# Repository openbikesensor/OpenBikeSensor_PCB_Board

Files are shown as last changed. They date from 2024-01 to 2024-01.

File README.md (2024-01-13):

# OpenBikeSensor PCB

Dieses Repository enthält die offiziellen PCBs des OpenBikeSensor Projektes.
Sie sind in der freien Software [KiCad](https://www.kicad.org/) erstellt und
können damit modifiziert werden.

## Versionen

### OpenBikeSensor

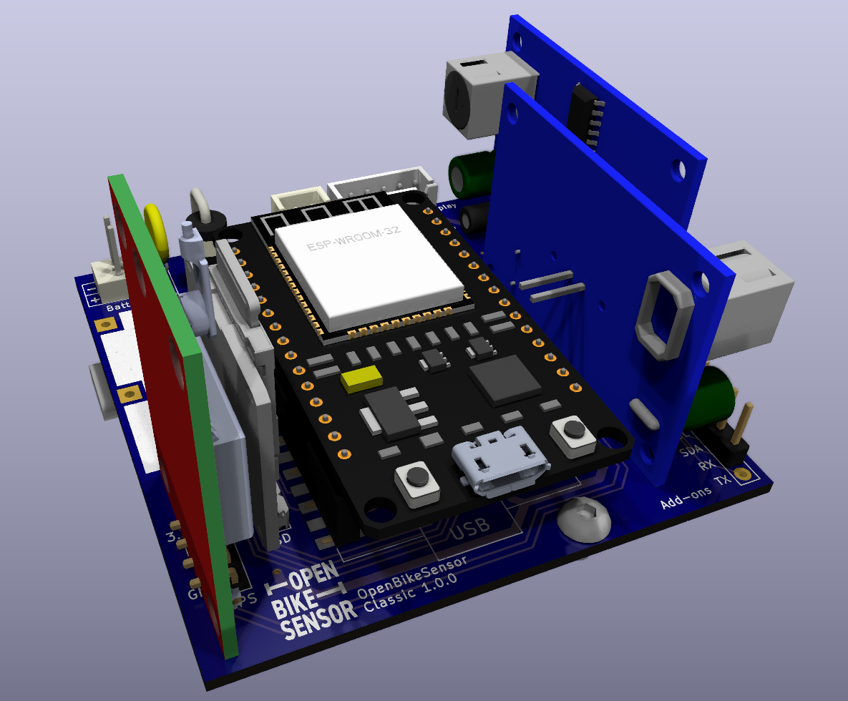
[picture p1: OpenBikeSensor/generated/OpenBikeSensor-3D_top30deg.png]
OpenBikeSensor 3D-Render


Dies ist der Standard-OpenBikeSensor als eigenständiges Gerät, hergestellt aus
vielen fertig verfügbaren Modulen (ESP32 Devkit, GPS, SD-Karten-Modul,
Ultraschallsensor-Module, ...).

Die aktuelle Versionsnummer des OpenBikeSensor Clasic PCB ist `1.0.0`. Den veralteten Repositorystand der Vorversion findest du [hier](https://github.com/openbikesensor/OpenBikeSensor_PCB_Board/tree/00.03.12)

* [Gerber](OpenBikeSensor1.0.0-Gerber.zip)
* [Schaltplan, PDF](./OpenBikeSensor/generated/OpenBikeSensor-1.0.0-schematic.pdf)
* [Bestückungsplan, HTML](./OpenBikeSensor/generated/OpenBikeSensor-1.0.0-ibom.html)

### OpenBikeSensor Lite

In naher Zukunft werden wir hier auch die PCB-Dateien des *OpenBikeSensor Lite*
veröffentlichen. Dies ist ein reduzierter Hardwareaufbau, in welchem nur der
ESP32, die zwei Sensormodule und ein Button enthalten sind, und welcher im
Zusammenspiel mit einem Smartphone die restlichen Daten sammeln kann. Dieses
Projekt ist zur Zeit in der Entwicklung und hoffentlich in der ersten
Jahreshälfte 2023 benutzbar.

### OpenBikeSensor Pro

Diese Variante des OpenBikeSensor ist ein vollständiger Nachbau aller
relevanter Teile der vorher als Modul gelieferten Funktionen in einer eigenen
Schaltung, und ist komplett maschinenbestückt bestellbar. Dies macht das Gerät
teurer und komplizierter herstellen zu lassen, aber es ist ein wesentlich
geringerer Eigenaufwand zur Fertigstellung ohne Löten elektronischer Module
nötig. Dieses Projekt is zur Zeit in der Entwicklung und hoffentlich im Laufe
des Jahres 2023 benutzbar.

## Bestellung bei Platinenherstellern

Ein Export der Projektdateien als "Gerber-Files" liegt im jeweiligen
Projektordner vor. Die meisten Hersteller von Platinen bieten einen
Online-Konfigurator an, in den diese Dateien hochgeladen werden können, und
welcher dann auch eine Vorschau bietet. In der Regel sollten diese Exports für
alle Hersteller funktionieren, die Anforderungen an die Genauigkeit der
Produktion sind relativ gering.

Die Standardeinstellungen für die Platine sind in der Regel vollkommen
ausreichend, das ist üblicherweise ein 2-Layer Board mit einfachem Surface
Finish (HASL) in 1.6mm Stärke (FR-4) und 1oz Kupferstärke. Bessere Optionen (z.
B. ENIG) sind möglich, aber nicht nötig. Die Einstellungen können nach Belieben
angepasst werden, insbesondere ästhetische Aspekte wie die Farbe der Boards.

Einige Hersteller (z. B. Aisler) können die KiCad-Dateien direkt importieren,
hier muss nur die `.kicad_pcb` Datei ausgewählt werden, diese enthält alle
Informationen des Designs.

Bei manchen Herstellern (z. B. JLCPCB) wird die Bestellnummer auf jedes Board
aufgedruckt, für einen kleinen Mehrbetrag kann dies vermieden werden. Gerade
bei größeren Bestellungen fällt diese Gebühr kaum ins Gewicht und ist sehr zu
empfehlen.

## Lizenz

Die eigenen Inhalte dieses Repositories sind lizensiert unter den Bedingungen
der GNU Lesser General Public License. Eine Kopie der Lizenz befindet sich in der
Datei `LICENSE` in diesem Verzeichnis.

Nicht unter diese Lizenz fallen:

* Die folgenden Dateien, welche leichte Modifikationen von Standard-Footprints
  der KiCad-Bibliothek sind und somit unter der entsprechende Lizenz
  ([CC-BY-SA 4.0 mit Modifikationen](https://www.kicad.org/libraries/license/))
  stehen:
    - `libs/OpenBikeSensor.pretty/CP_Radial_D4.0mm_P1.50mm.kicad_mod`
    - `libs/OpenBikeSensor.pretty/Connector_1x02.kicad_mod`
    - `libs/OpenBikeSensor.pretty/Connector_1x04.kicad_mod`
    - `libs/OpenBikeSensor.pretty/Connector_1x05_Display.kicad_mod`
    - `libs/OpenBikeSensor.pretty/Connector_1x06.kicad_mod`

## Update der Exportdateien

Die Dateien in `generated` können mit
[KiBot](https://github.com/INTI-CMNB/KiBot) automatisch aktualisiert werden.
Eine Konfigurationsdatei liegt im jeweiligen Projektverzeichnis vor. Ein
Ausführen von `kibot` im entsprechenden Unterverzeichnis (z. B. `cd
OpenBikeSensor`) erstellt alle Exportdateien neu. Bitte checke nur solche
Dateien in git ein, welche du in deinem Commit auch inhaltlich verändert hast
(z. B. den PDF Schaltplanexport wenn der Schaltplan verändert wurde, aber nicht
wenn nur das PCB Änderungen hat).

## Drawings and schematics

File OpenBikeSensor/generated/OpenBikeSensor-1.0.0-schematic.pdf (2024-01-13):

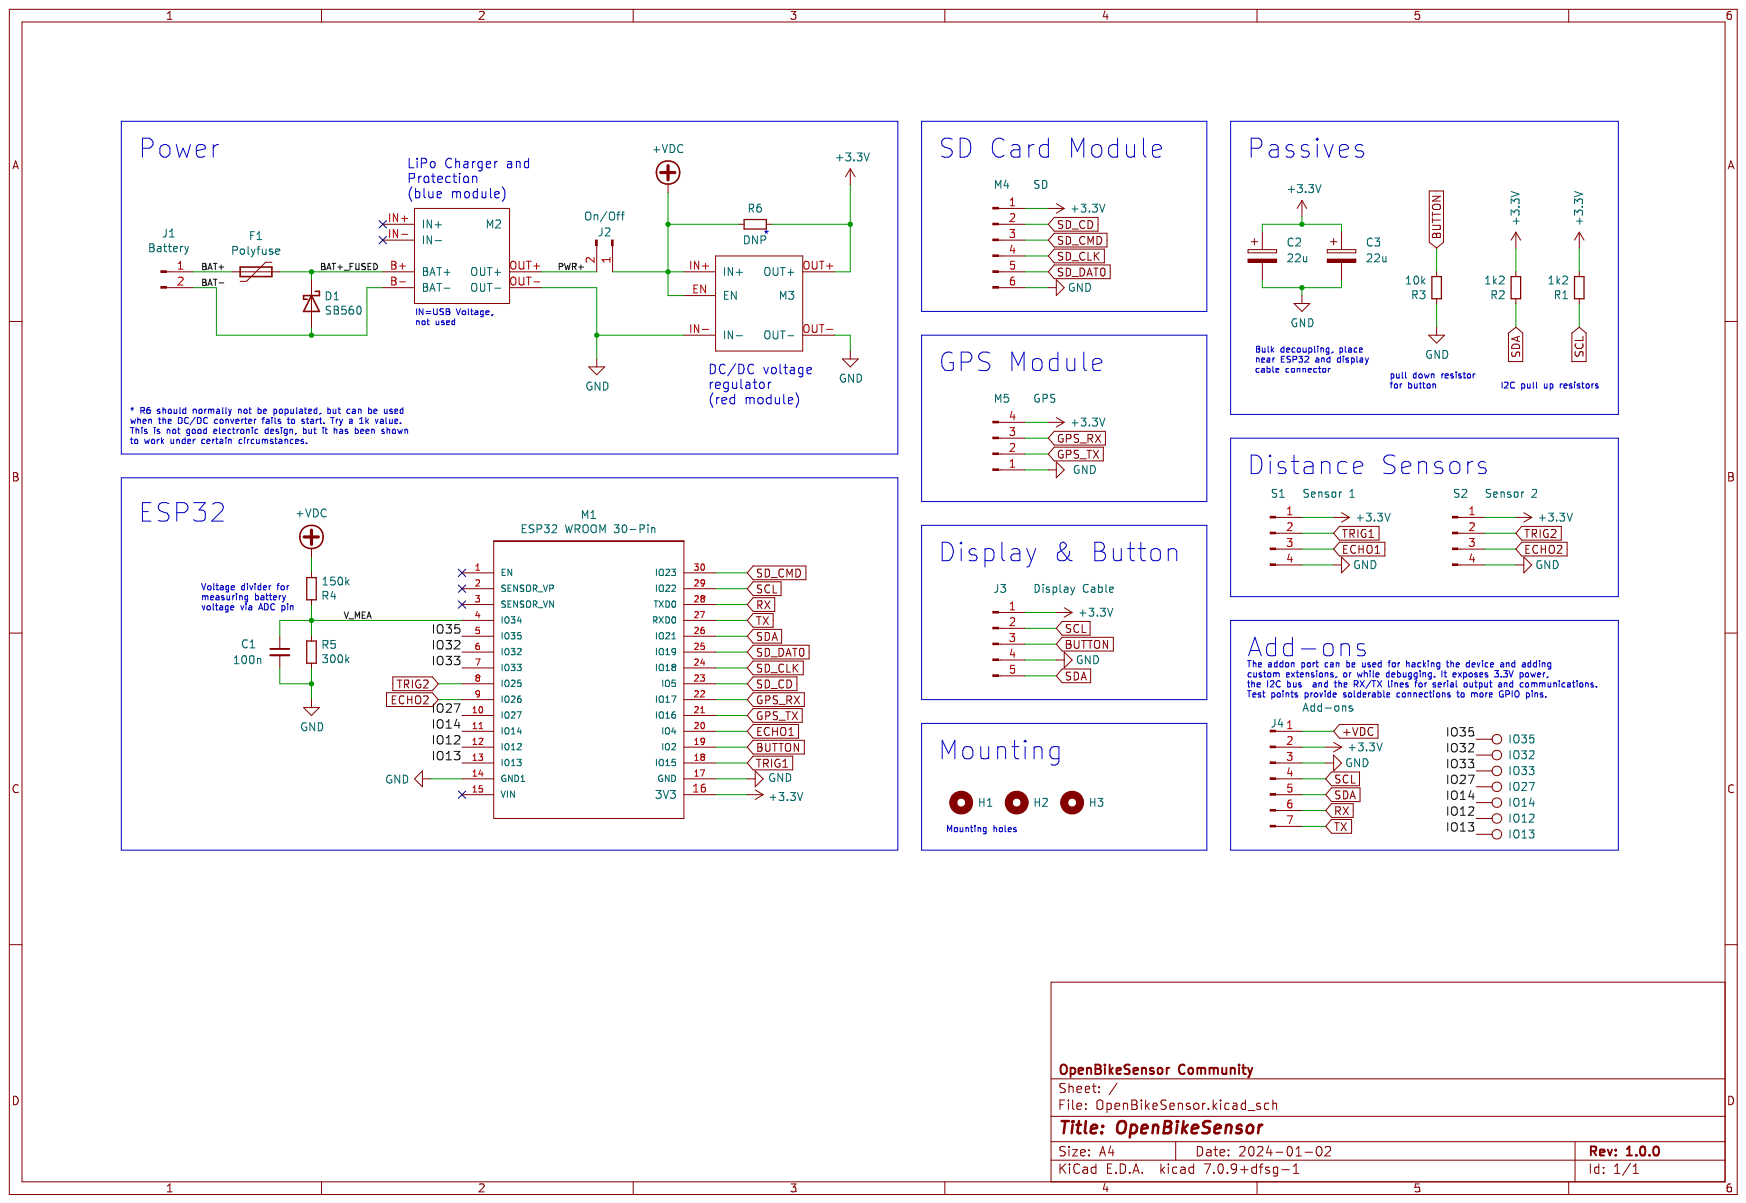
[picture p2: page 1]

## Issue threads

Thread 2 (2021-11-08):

Feature request: update parts list to match current board layout

gluap, 2021-11-08:
The [parts list from this repo](https://github.com/openbikesensor/OpenBikeSensor_PCB_Board/tree/merged/OpenBikeSensor03/generated)  would come in handy as a soldering help in the soldering documentation. Unfortunately it is currently outdated (gerber for 0.03.12, board html for 0.03.10)

We should have the html board beowser match the current version of the board so it could be linked on the soldering documentation -- fixing also [this issue](https://github.com/openbikesensor/openbikesensor.github.io/issues/107) by @notudu

There's a nice htmlpreview feature that would allow to direct-link the html from this repo over in the website repo
[like so](http://htmlpreview.github.io/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)

Closed 2022-01-05.

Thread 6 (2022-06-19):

Connections of DC-DC-converter on PCB

morellenfeuer, 2022-06-19:
A simple improvement would be to print the connections of the DC-DC converter on the PCB. I had one with reversed out outputs and had searched a bit long for the short circuit, because I had not expected it.

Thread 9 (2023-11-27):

Was ist das aktuelle board?

mxa, 2023-11-27:
Im Readme steht: "Aktuelle Version ist das “OpenBikeSensor_pcb_flippedPower_b.pro”.
Aktueller Branch: “Mit_Verpolschutz”
Dort ist aber Rev 00.02.08 auf dem Silkscreen.

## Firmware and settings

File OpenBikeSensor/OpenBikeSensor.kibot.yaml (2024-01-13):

kibot:
  version: 1

global:
  out_dir: generated

outputs:

- name: basic_pdf_sch_print
  comment: Schematic in PDF format
  type: pdf_sch_print
  dir: .

- name: basic_ibom
  comment: Interactive HTML BoM
  type: ibom
  dir: .

- name: JLCPCB_gerbers
  comment: Gerbers compatible with JLCPCB
  type: gerber
  dir: Manufacturers/JLCPCB/Gerbers
  options:
    exclude_edge_layer: true
    exclude_pads_from_silkscreen: true
    plot_sheet_reference: false
    plot_footprint_refs: true
    plot_footprint_values: false
    force_plot_invisible_refs_vals: false
    tent_vias: true
    use_protel_extensions: true
    create_gerber_job_file: false
    disable_aperture_macros: true
    gerber_precision: 4.6
    use_gerber_x2_attributes: false
    use_gerber_net_attributes: false
    line_width: 0.1
    subtract_mask_from_silk: true
    inner_extension_pattern: .gp%n
  layers: &layers_jlc
  - layer: F.Cu
    suffix: F_Cu
    description: Front copper
  - layer: B.Cu
    suffix: B_Cu
    description: Bottom copper
  - layer: B.Paste
    suffix: B_Paste
    description: Bottom solder paste
  - layer: F.Paste
    suffix: F_Paste
    description: Front solder paste
  - layer: B.Silkscreen
    suffix: B_Silkscreen
    description: Bottom silkscreen (artwork)
  - layer: F.Silkscreen
    suffix: F_Silkscreen
    description: Front silkscreen (artwork)
  - layer: B.Mask
    suffix: B_Mask
    description: Bottom soldermask (negative)
  - layer: F.Mask
    suffix: F_Mask
    description: Front soldermask (negative)
  - layer: Edge.Cuts
    suffix: Edge_Cuts
    description: Board shape
- name: JLCPCB_drill
  comment: Drill files compatible with JLCPCB
  type: excellon
  dir: Manufacturers/JLCPCB/Gerbers
  options:
    pth_and_npth_single_file: false
    pth_id: -PTH
    npth_id: -NPTH
    metric_units: true
    map: gerber
    route_mode_for_oval_holes: false
    output: '%f%i.%x'
- name: JLCPCB
  comment: ZIP file for JLCPCB
  type: compress
  dir: Manufacturers/JLCPCB
  options:
    files:
    - from_output: JLCPCB_gerbers
      dest: /
    - from_output: JLCPCB_drill
      dest: /

- name: basic_excellon
  comment: Drill files in EXCELLON format
  type: excellon
  dir: Manufacturers/Generic/Gerbers
  options:
    map: pdf
- name: basic_gerb_drill
  comment: Drill files in GERB_DRILL format
  type: gerb_drill
  dir: Manufacturers/Generic/Gerbers
  options:
    map: gerber
- name: gerber_modern
  comment: Gerbers in modern format, recommended by the standard
  type: gerber
  dir: Manufacturers/Generic/Gerbers
  layers:
  - layer: F.Cu
    suffix: F_Cu
    description: Front copper
  - layer: B.Cu
    suffix: B_Cu
    description: Bottom copper
  - layer: B.Paste
    suffix: B_Paste
    description: Bottom solder paste
  - layer: F.Paste
    suffix: F_Paste
    description: Front solder paste
  - layer: B.Silkscreen
    suffix: B_Silkscreen
    description: Bottom silkscreen (artwork)
  - layer: F.Silkscreen
    suffix: F_Silkscreen
    description: Front silkscreen (artwork)
  - layer: B.Mask
    suffix: B_Mask
    description: Bottom soldermask (negative)
  - layer: F.Mask
    suffix: F_Mask
    description: Front soldermask (negative)
  - layer: User.Drawings
    suffix: User_Drawings
    description: User drawings
  - layer: User.Comments
    suffix: User_Comments
    description: User comments
  - layer: Edge.Cuts
    suffix: Edge_Cuts
    description: Board shape
  - layer: F.Courtyard
    suffix: F_Courtyard
    description: Front courtyard area
  - layer: B.Fab
    suffix: B_Fab
    description: Bottom documentation
  - layer: F.Fab
    suffix: F_Fab
    description: Front documentation


- name: gerber_modern_zip
  comment: ZIP file for Gerbers
  type: compress
  dir: Manufacturers/Generic
  options:
    files:
    - from_output: basic_excellon
      dest: /
    - from_output: basic_gerb_drill
      dest: /
    - from_output: gerber_modern
      dest: /

# Disabled because SVG renderer crashes :(

# - name: render_pcb_top
#   comment: PCB 2D render, Top side
#   type: pcbdraw
#   dir: .
#   options:
#     style: set-blue-enig
#     format: png
#     bottom: false
#
# - name: render_pcb_bottom
#   comment: PCB 2D render, Bottom side
#   type: pcbdraw
#   dir: .
#   options:
#     style: set-blue-enig
#     format: png
#     bottom: true

- name: basic_render_3d
  comment: 3D view from 30 degrees
  type: render_3d
  dir: .
  output_id: 30deg
  options:
    ray_tracing: false
    rotate_x: 5
    rotate_z: -2
    width: 1920
    height: 1920
    solder_mask: '#022a8e'

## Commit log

2020-06-02 Initial state OpenBikeSensor_pcb_flippedPower_b.pro is current version
    [OpenBikeSensor_pcb.kicad_pcb, OpenBikeSensor_pcb.sch, OpenBikeSensor_pcb_flippedPower.kicad_pcb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]
2020-06-04 Added MT3608 --> PCB NOT ready!
    splitted schematic in 2 sheets. power + rest
    [OpenBikeSensor_PowerPart.sch, OpenBikeSensor_pcb_flippedPower_b.kicad_pcb, OpenBikeSensor_pcb_flippedPower_b.sch]
2020-06-04 Powerpart outsourced in extra sheet und Schematic fixed
    printed new schematic pdf
    [OpenBikeSensor_PowerPart.sch, OpenBikeSensor_pcb_flippedPower_b.sch]
2020-06-04 MT3608 finished LM2596 removed LM285 moved
    [OpenBikeSensor_PowerPart.sch, OpenBikeSensor_pcb_flippedPower_b.kicad_pcb, OpenBikeSensor_pcb_flippedPower_b.sch]
2020-06-04 Elkos for SD Card added spme silk fixed all parts locked in position
    [OpenBikeSensor_pcb_flippedPower_b.kicad_pcb, OpenBikeSensor_pcb_flippedPower_b.sch]
2020-06-05 Panic Pullups for I2C added (in 0805) Gerber for JLCPCB added
    [OpenBikeSensor_pcb_flippedPower_b.kicad_pcb, OpenBikeSensor_pcb_flippedPower_b.sch]
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2020-06-06 OpenBikeSensor logo added :)
    [OpenBikeSensor_pcb_flippedPower_b.kicad_pcb]
2020-06-07 Connector for Neo-6M updated Now compatible with both variants of connectors
    [OpenBikeSensor_pcb_flippedPower_b.kicad_pcb, OpenBikeSensor_pcb_flippedPower_b.sch]
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2020-06-09 Backup Package für ESP32 eingepflegt.
    [OpenBikeSensor_pcb_flippedPower_b.kicad_pcb]
2020-06-09 DRC errors resolved
    [OpenBikeSensor_pcb_flippedPower_b.kicad_pcb]
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2020-06-10 Improved 1 Track (0,2mm to 0,5mm)
    [OpenBikeSensor_pcb_flippedPower_b.kicad_pcb]
2020-06-10 Improved some more tracks
    [OpenBikeSensor_pcb_flippedPower_b.kicad_pcb]
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2020-06-11 Backup Pins added (6 IOs Vcc GND)
    [OpenBikeSensor_PowerPart.sch, OpenBikeSensor_pcb_flippedPower_b.kicad_pcb, OpenBikeSensor_pcb_flippedPower_b.sch]
2020-06-12 Added THT Holes to Backup Pins J10
    [OpenBikeSensor_pcb_flippedPower_b.kicad_pcb]
2020-06-12 OBS Logo on top moved
    [OpenBikeSensor_pcb_flippedPower_b.kicad_pcb]
2020-06-17 Cleaned up 2 Tracks
    [OpenBikeSensor_pcb_flippedPower_b.kicad_pcb]
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2020-07-11 uodated BOM updated 3V3 to small trace
    [OpenBikeSensor_pcb_flippedPower_b.kicad_pcb]
2020-07-11 Improved (bad) 3V3 plane a little bit
    [OpenBikeSensor_pcb_flippedPower_b.kicad_pcb]
2020-07-11 Improved 3V3 plane some more
    [OpenBikeSensor_pcb_flippedPower_b.kicad_pcb]
2020-07-12 fixed a bug regarding gerber export
    [OpenBikeSensor_pcb_flippedPower_b.kicad_pcb]
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2020-07-15 Fixed some BOM issues
2020-07-17 Updated SMD Pads at SEPIC
    [OpenBikeSensor_pcb_flippedPower_b.kicad_pcb]
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2020-07-18 Drill holes for D2 were too small (1.1mm instead of >1.2mm)
    [OpenBikeSensor_pcb_flippedPower_b.kicad_pcb]
2020-07-27 fixed rotated ESP32 Board
    [OpenBikeSensor_pcb_flippedPower_b.kicad_pcb]
2020-08-01 updatet to 0.2.03
    switched from voltage reference to n-fet for gps module
    [OpenBikeSensor_pcb_flippedPower_b.kicad_pcb]
2020-08-09 Corrected Position of Battery Connector Updated Gerber to 0.02.04
    [OpenBikeSensor_pcb_flippedPower_b.kicad_pcb, OpenBikeSensor_pcb_flippedPower_b.sch]
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2020-08-09 fixed defective file
    [OpenBikeSensor_pcb_flippedPower_b.kicad_pcb]
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2020-08-09 Added version for new KiCad
    [OpenBikeSensor_pcb_flippedPower_b_u.kicad_pcb]
2020-08-09 fixed Model for MT3608 Buck Boost Sepic in pcb
    [OpenBikeSensor_pcb_flippedPower_b.kicad_pcb]
2020-08-09 add new US sensor boards to the PCB
    [OpenBikeSensor_pcb_flippedPower_b_u.kicad_pcb]
2020-08-09 fixed geometry paths
    [OpenBikeSensor_pcb_flippedPower_b.kicad_pcb]
2020-08-16 Improved D2 placement, updated board and gerber to 00.02.05
    [OpenBikeSensor_pcb_flippedPower_b.kicad_pcb]
2020-08-16 fixed small silk bug
    [OpenBikeSensor_pcb_flippedPower_b.kicad_pcb]
2020-08-17 deleted 2 orphan traces
    [OpenBikeSensor_pcb_flippedPower_b.kicad_pcb, OpenBikeSensor_pcb_flippedPower_b_u.kicad_pcb]
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2020-08-18 fixed boundary
    [OpenBikeSensor_pcb_flippedPower_b_u.kicad_pcb]
2020-08-19 added more srew holes improved ground/vcc planes updated 3D Models
    [OpenBikeSensor_pcb_flippedPower_b_u.kicad_pcb]
2020-08-19 updated wrong Diode Package of D2 in schematic
    [OpenBikeSensor_PowerPart.sch]
2020-08-19 updated D2 to DO-201 package
    [OpenBikeSensor_PowerPart.sch]
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2020-08-19 fixed mistake in esp footprint fixed problem with diode
    [OpenBikeSensor_pcb_flippedPower_b_u.kicad_pcb]
2020-08-19 updated footprint of ESP32 gerber needs to be done
    [OpenBikeSensor_pcb_flippedPower_b.kicad_pcb]
2020-08-19 fixed 3D model postions in ESP32
    [OpenBikeSensor_pcb_flippedPower_b_u.kicad_pcb]
2020-08-19 fixed esp32 footprint and generated Gerber updated to 00.02.06
    [OpenBikeSensor_pcb_flippedPower_b.kicad_pcb]
2020-08-20 sticked the USB Con a little bit more out Updated to 00.02.07
    [OpenBikeSensor_pcb_flippedPower_b.kicad_pcb]
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2020-08-23 fixed typo in plain text of Pos7 of BOM for ordering
2020-08-23 fixed Typo in pos7 of BOM for ordering again
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2020-09-03 Switched GPS transistor to IO12 Updatet schematic and gerbers update 00.02.08
    [OpenBikeSensor_pcb_flippedPower_b.kicad_pcb, OpenBikeSensor_pcb_flippedPower_b.sch]
2020-09-03 Switched transistor Pin from IO35 to IO12 Updatet schematic, board and Gerber updated to 00.03.10
    [OpenBikeSensor_pcb_flippedPower_b.kicad_pcb, OpenBikeSensor_pcb_flippedPower_b.sch]
2020-09-03 fixed wrong silk at J10 (IO12 to IO35)
    [OpenBikeSensor_pcb_flippedPower_b.kicad_pcb]
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2020-09-28 fixed false link to resistor R2 R3 in BOM added 18650 cell to BOM
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2020-10-26 Updated BOM_for_soldering_Rev_0.03.10.html "Bemerkungen" have to be updated!
    [OpenBikeSensor_pcb_flippedPower_b.sch]
2020-12-23 clean up model references and add missing libraries
    [OpenBikeSensor_PowerPart.sch, OpenBikeSensor_pcb_flippedPower_b.kicad_pcb, OpenBikeSensor_pcb_flippedPower_b.sch]
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2020-12-23 move project to subfolder
    [OpenBikeSensor03.kicad_pcb, OpenBikeSensor03.sch, OpenBikeSensor03_PowerPart.sch]
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2020-12-23 Fix symbols and footprint references, add missing library
    [OpenBikeSensor02.kicad_pcb, OpenBikeSensor02.sch, OpenBikeSensor02_PowerPart.sch]
2020-12-23 03: fix reference to SD card model
    [OpenBikeSensor03.kicad_pcb]
2020-12-27 fixed the polarized cap to the 5.x libs
    [OpenBikeSensor02.sch]
2020-12-27 fixed bug in the SMD Micro SD Slot
2020-12-27 fixed bug in Micro SD Slot lib
2020-12-29 fixed wiring of the Micro SD slot
    [OpenBikeSensor03.kicad_pcb]
2020-12-29 increased Rev to 00.02.09 generated new Gerber
    [OpenBikeSensor02.kicad_pcb]
2020-12-29 Updated polarized Caps in schematic increased Revision to 00.03.11 updated Gerbers
    [OpenBikeSensor03.kicad_pcb, OpenBikeSensor03.sch]
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2021-01-25 updated schematic pdf export for both variants
    [OpenBikeSensor02.sch]
2021-03-22 Fixed some PCB issues Transistor ganz raus oder neue Komponente oder optional mit extra THT für Brück
    Via direkt an C3
    C3 weiter weg?
    J10 nicht THT wegen Kurzschlussmöglichkeit
    [OpenBikeSensor03.kicad_pcb, OpenBikeSensor03.sch]
2021-04-11 Fixed some more little spots in 00.03.xx
    [OpenBikeSensor03.kicad_pcb, OpenBikeSensor03.sch, OpenBikeSensor03_PowerPart.sch]
2021-04-26 work in progress save. Trying to fix J7 that switched falsly to 1x05 instead of 1x06
    [OpenBikeSensor03.kicad_pcb, OpenBikeSensor03.sch]
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2021-04-26 updated schematic for 00.03.12 (in some former version a Bug in J7 (5 instead of 6 pins) and in C2 (was marked as e1) occured)
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2021-04-26 fixed clearence DRC error in 00.03.12
    [OpenBikeSensor03.kicad_pcb]
2021-11-08 Add missing BOM for soldering 0.03.12
2022-01-08 Add Comment about R6 on Bottom of the board to eeschemafile and bom
    [OpenBikeSensor03.sch]
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2022-11-07 Turn around R1/R2/C1 labels and swap R1/R2 placement
    [OpenBikeSensor03.kicad_pcb]
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2022-11-15 Inline 3D models and fix paths
    [OpenBikeSensor.kicad_pcb, OpenBikeSensor.kicad_sch]
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2022-11-15 Fix filename for model of hex screw
    [OpenBikeSensor.kicad_pcb]
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2022-11-17 Reduce pad size of capacitors to separate masks
    [OpenBikeSensor.kicad_pcb]
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2022-11-21 Move some traces and vias around, fix sizing
    [OpenBikeSensor.kicad_pcb]
2022-11-24 Add silkscreen labels for many pins on the back
    [OpenBikeSensor.kicad_pcb]
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2022-12-01 Fix some silkscreen problems
    [OpenBikeSensor.kicad_pcb]
2022-12-01 Shrink board outline, space traces a bit more apart
    [OpenBikeSensor.kicad_pcb]
2022-12-01 Use GPS without black plastic spacers, move around a bit
    [OpenBikeSensor.kicad_pcb]
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2023-02-20 Add R6, an optional starter resistor for the DC/DC converter
    [OpenBikeSensor.kicad_pcb, OpenBikeSensor.kicad_sch]
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2023-07-18 add Ibom and schema, move one via away from "dangerously close to pad"
    [OpenBikeSensor.kicad_pcb]
2024-01-02 - Up the version number to 1.0.0 - Also in generated files - Remove old files inconsistent with current version.
    [OpenBikeSensor.kicad_pcb, OpenBikeSensor.kicad_sch]
